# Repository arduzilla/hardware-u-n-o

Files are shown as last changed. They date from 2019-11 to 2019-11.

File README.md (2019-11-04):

# hardware-u-n-o

Arduino Uno format board

- Microconroller: STM32H750VB 
  - 416MHz Clock (Max 480)
  - Code & Data cache
  - 1MB SRAM
  - 128KB Flash + 2MB QSPI (direct execution from the QSPI)
  - plenty of peripherals
- RS485
- 6x Servo connector
- ... and much more

how to edit the schematics and the board layout:

install Eagle (free software for non commercial use)  https://www.autodesk.co.uk/products/eagle/free-download

clone (or fork) the arduzilla repo:
```
git clone https://github.com/arduzilla/hardware-u-n-o.git
```

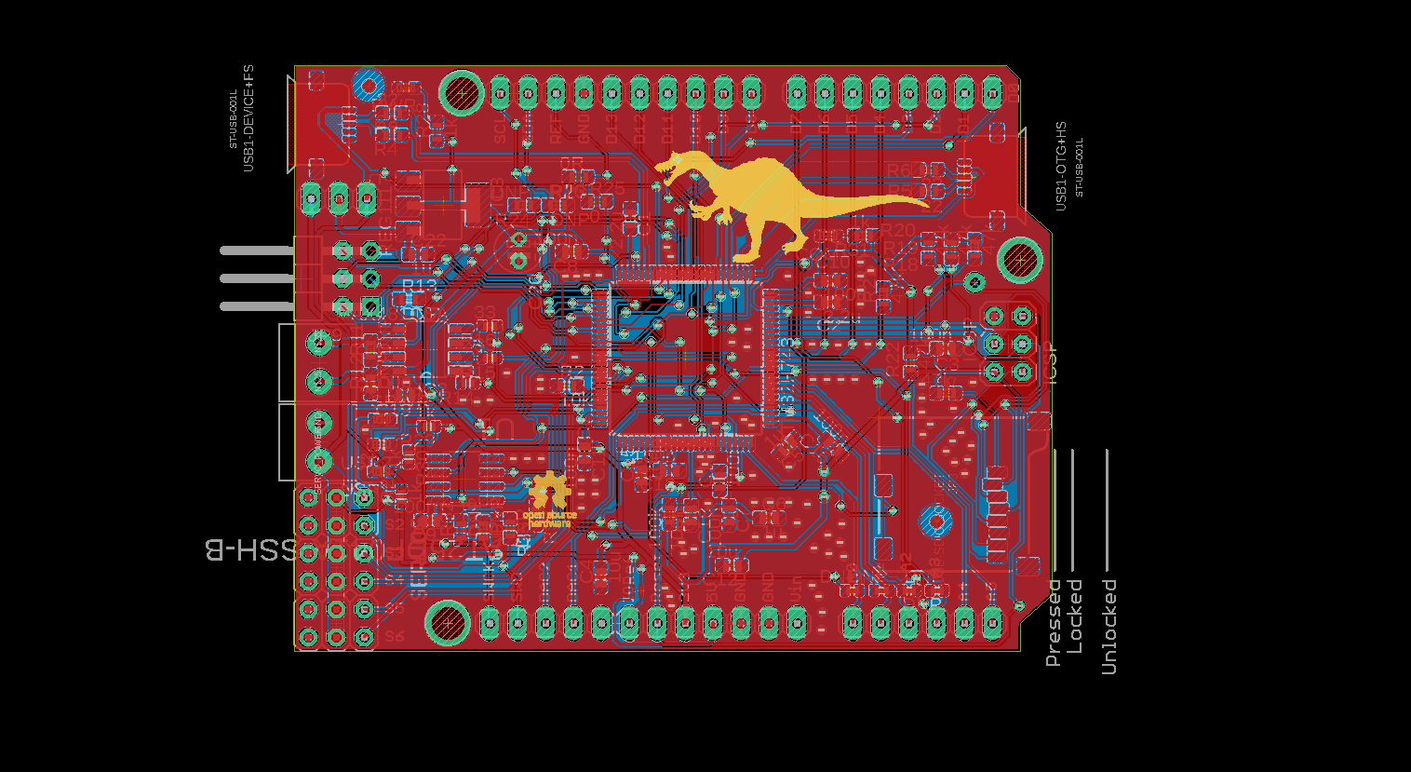
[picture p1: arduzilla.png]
arduzilla


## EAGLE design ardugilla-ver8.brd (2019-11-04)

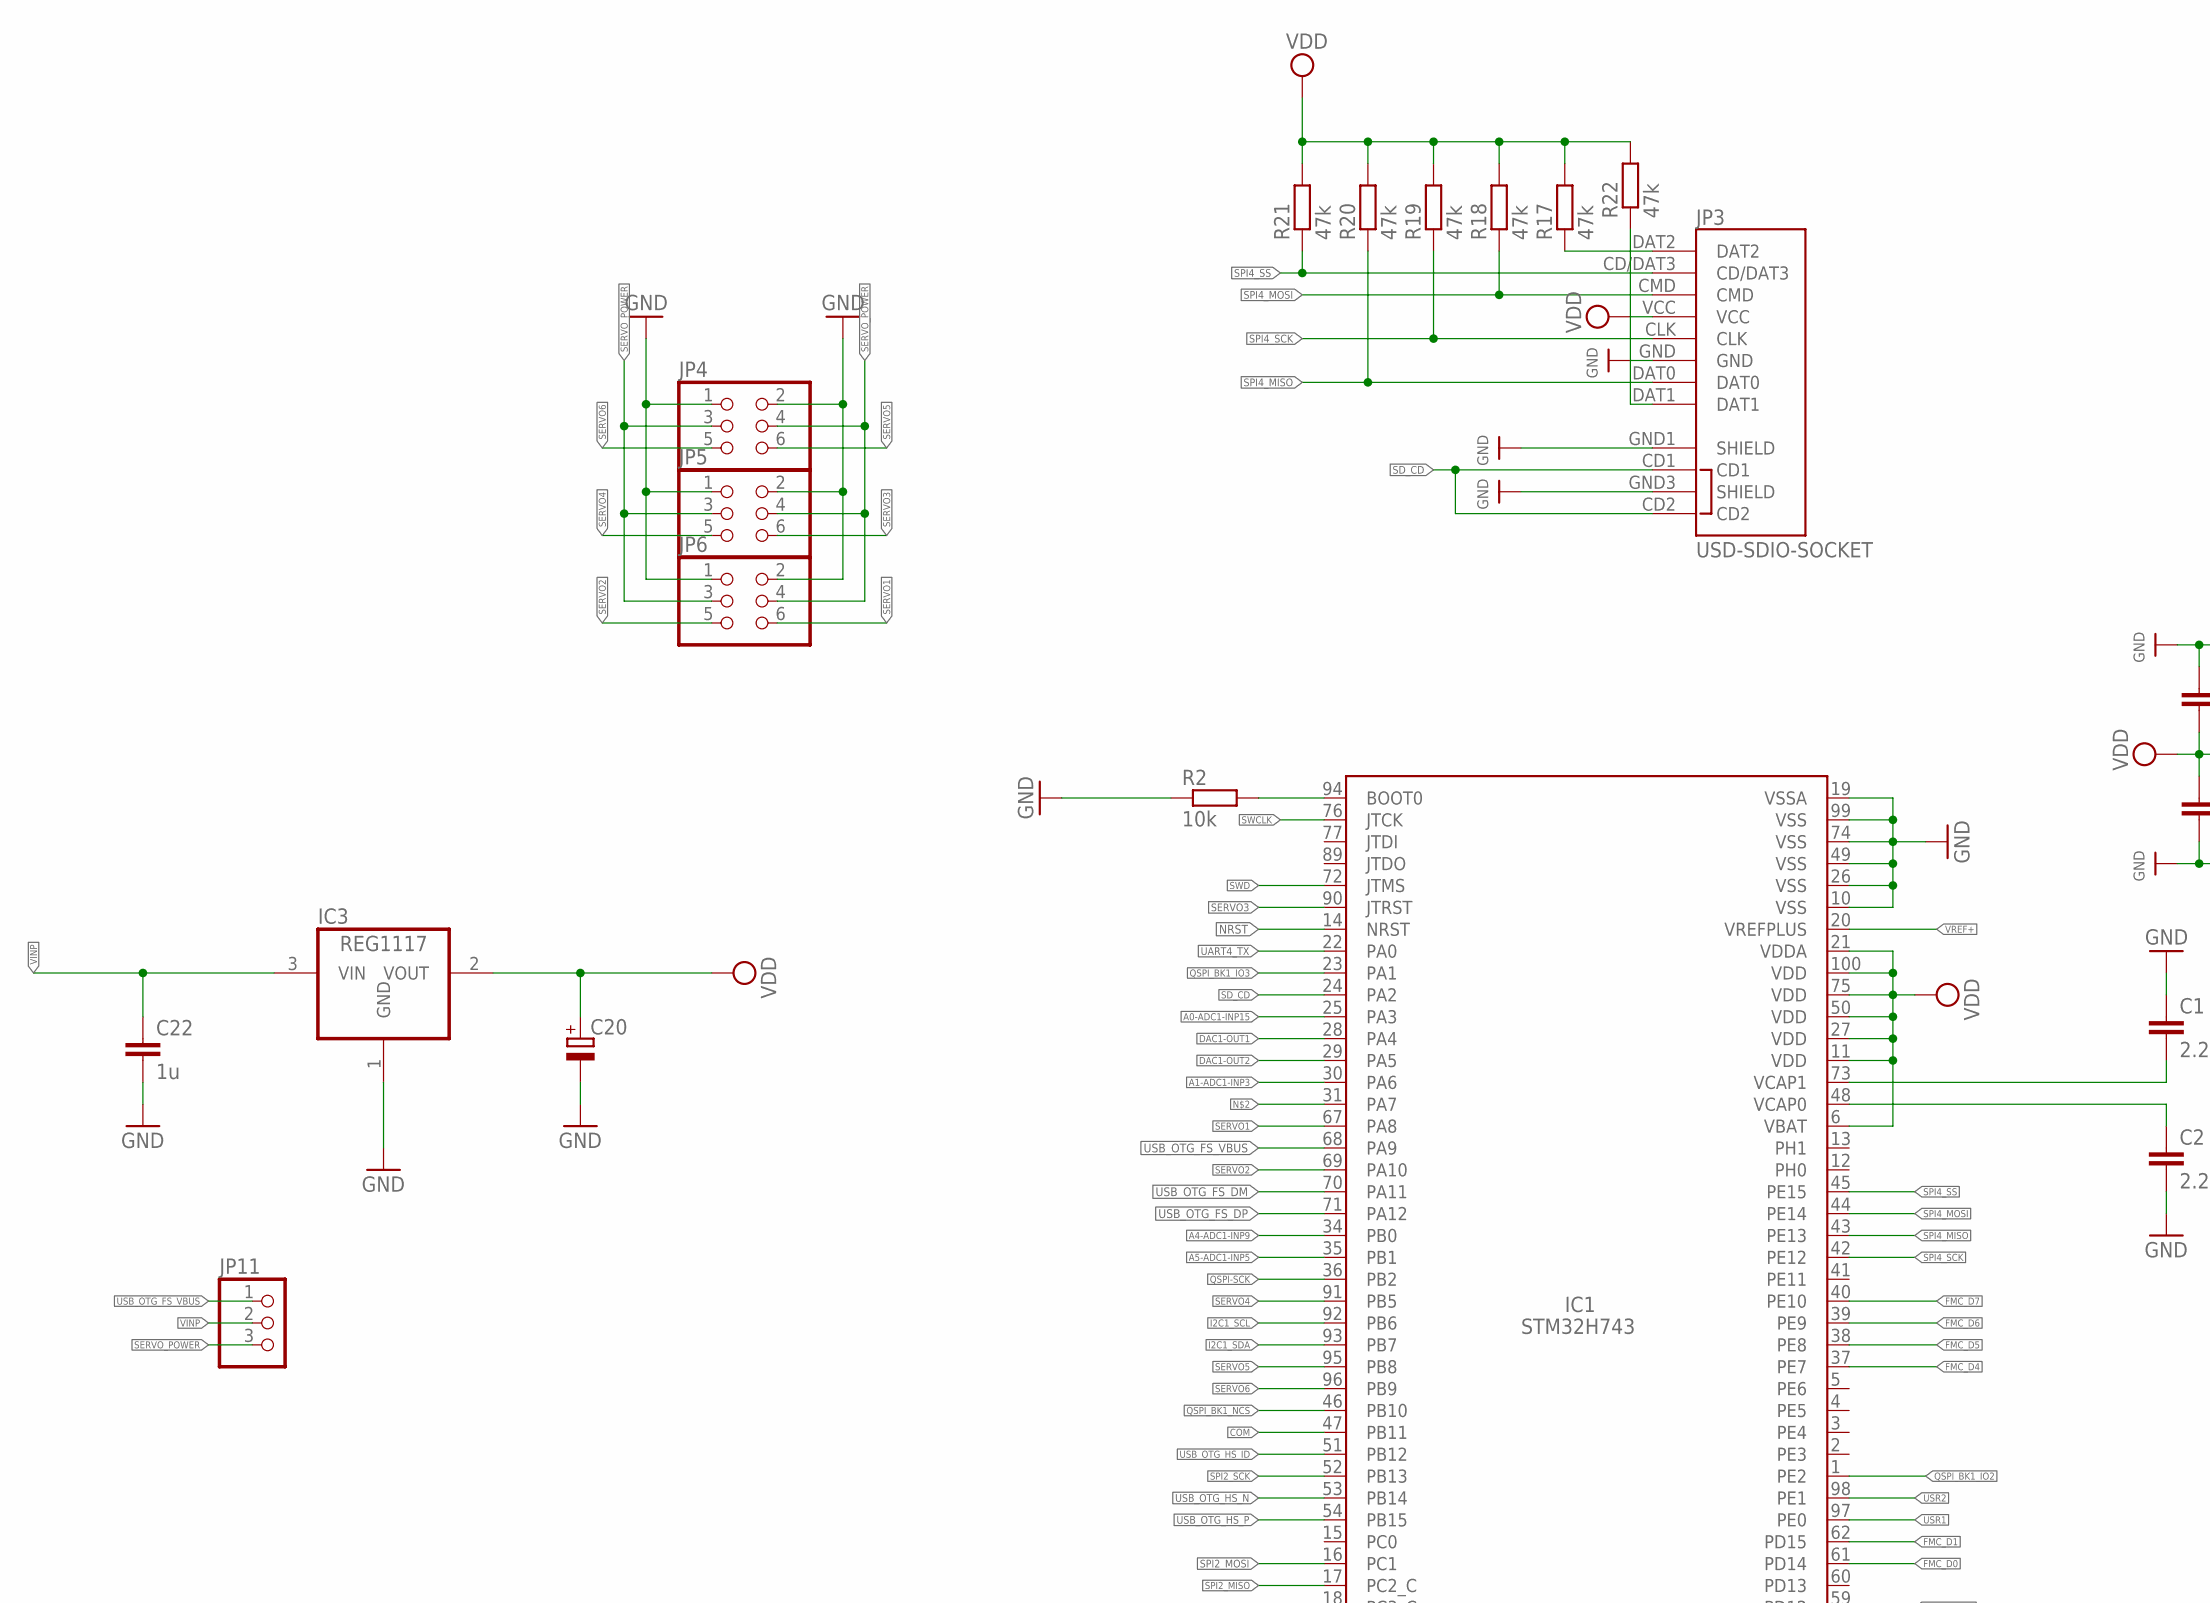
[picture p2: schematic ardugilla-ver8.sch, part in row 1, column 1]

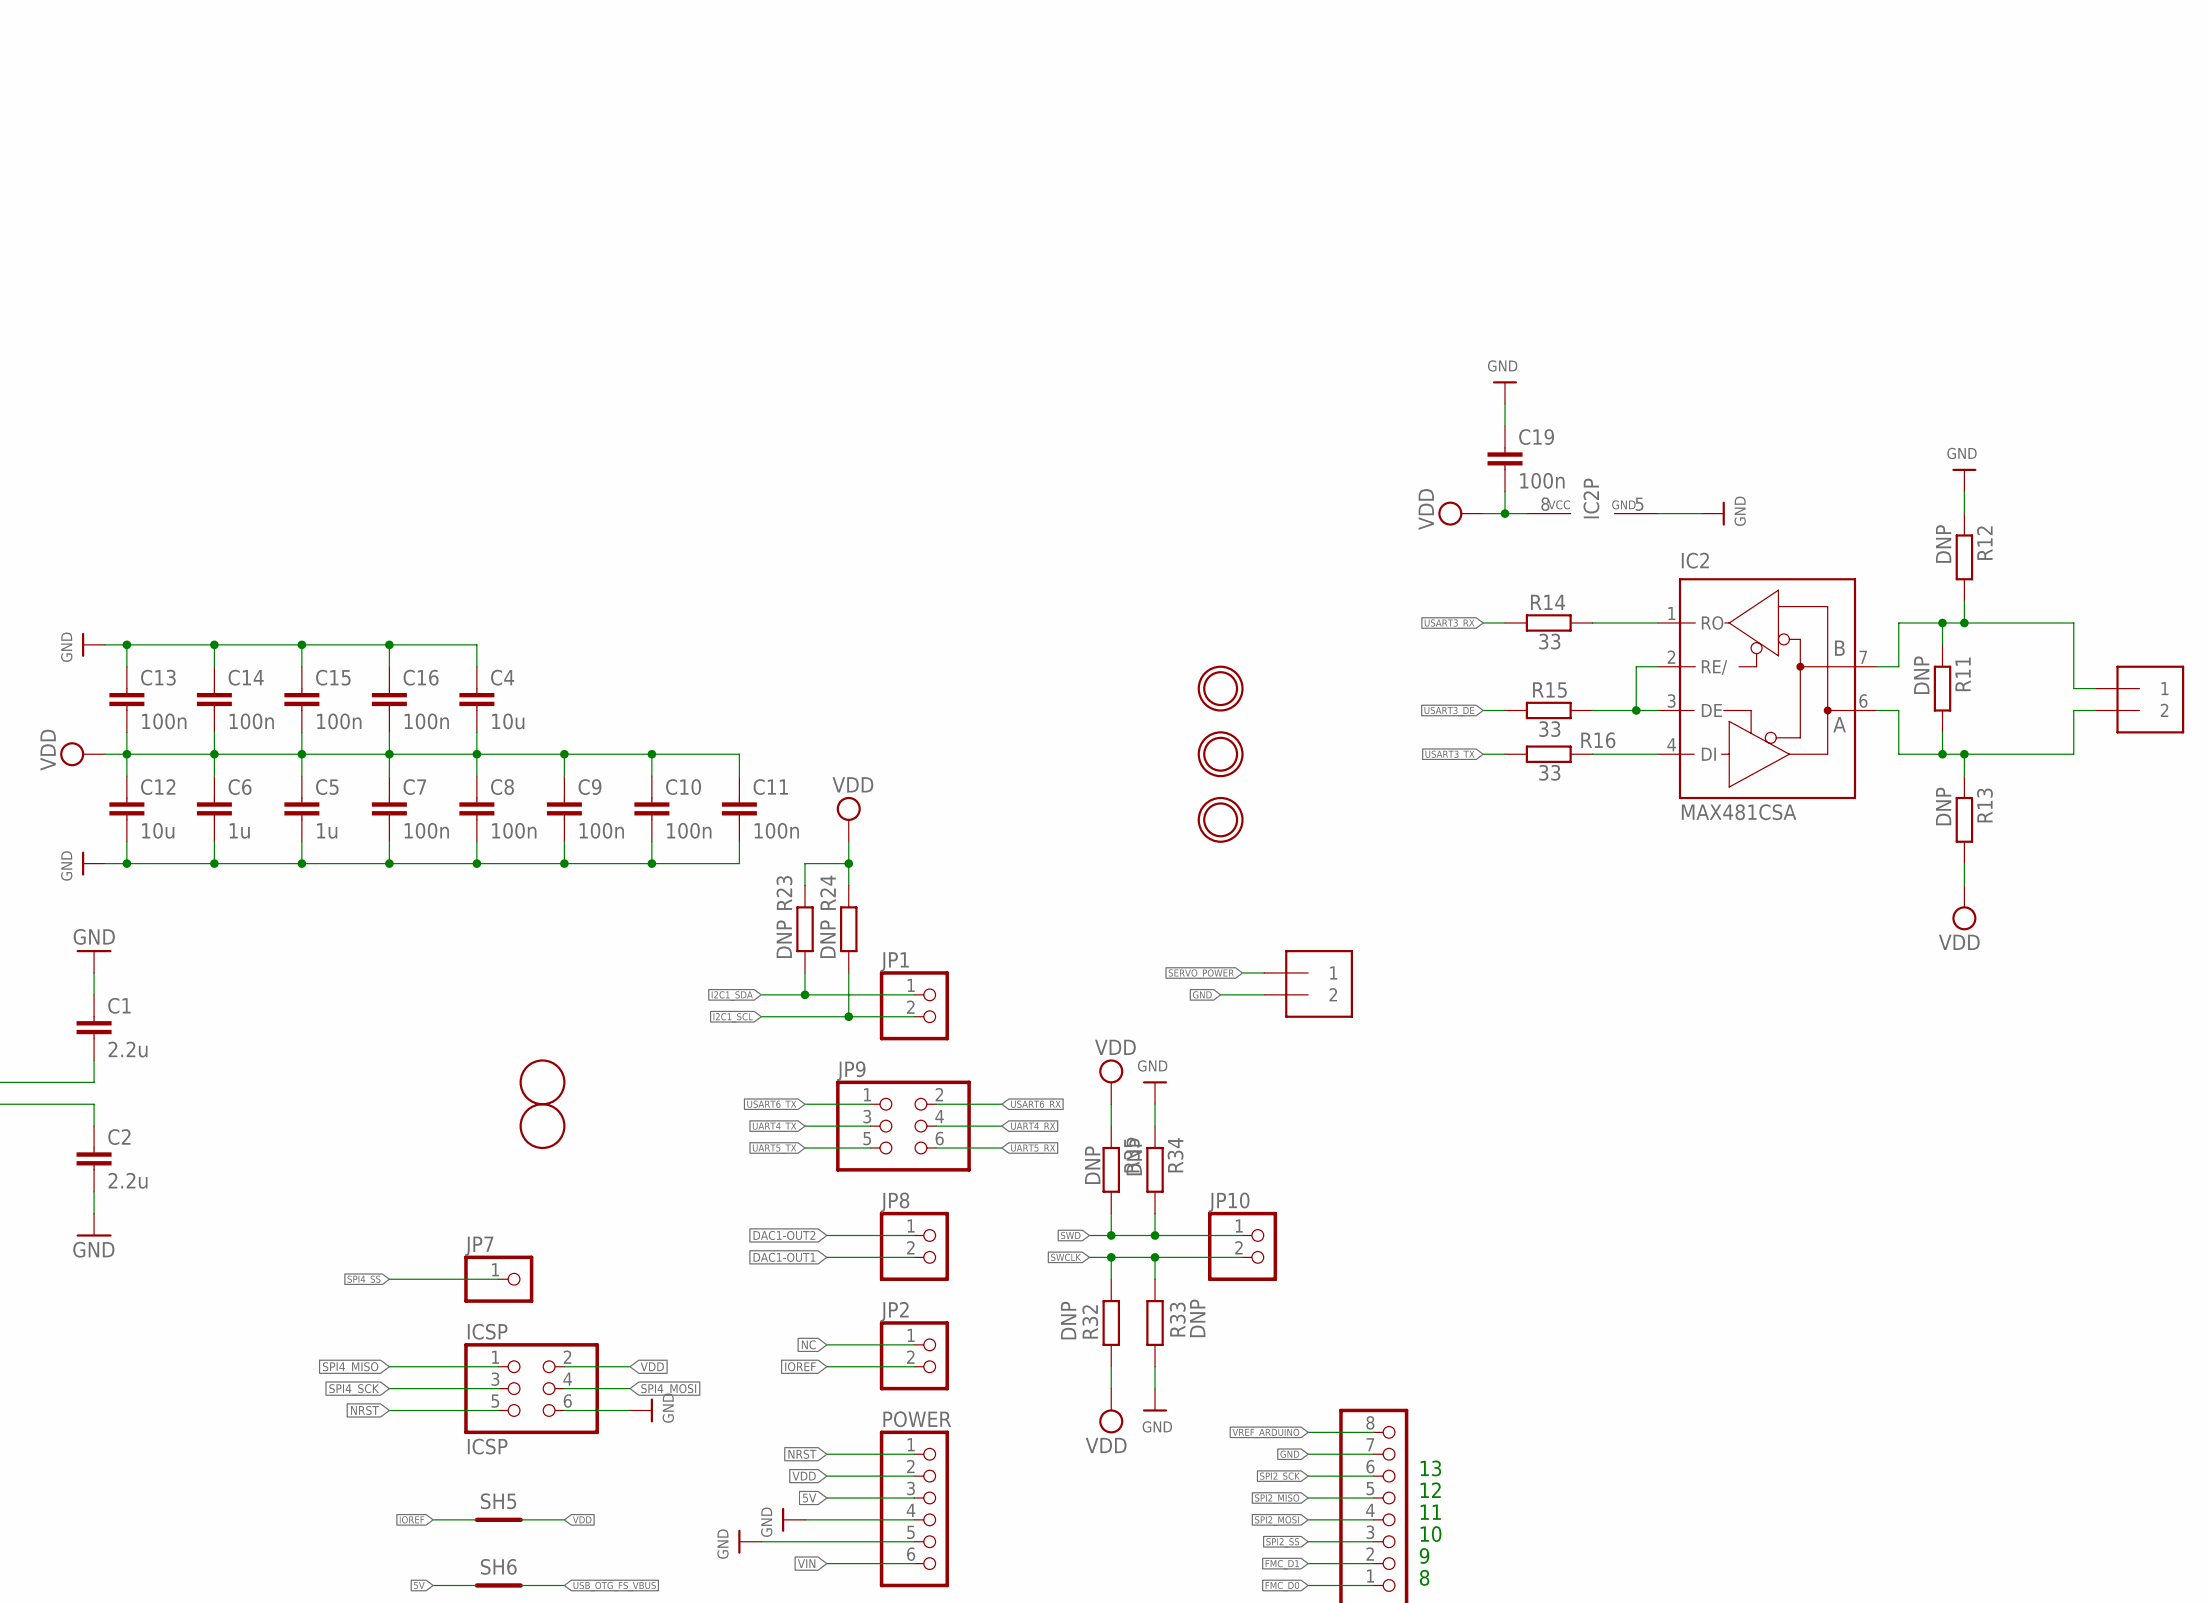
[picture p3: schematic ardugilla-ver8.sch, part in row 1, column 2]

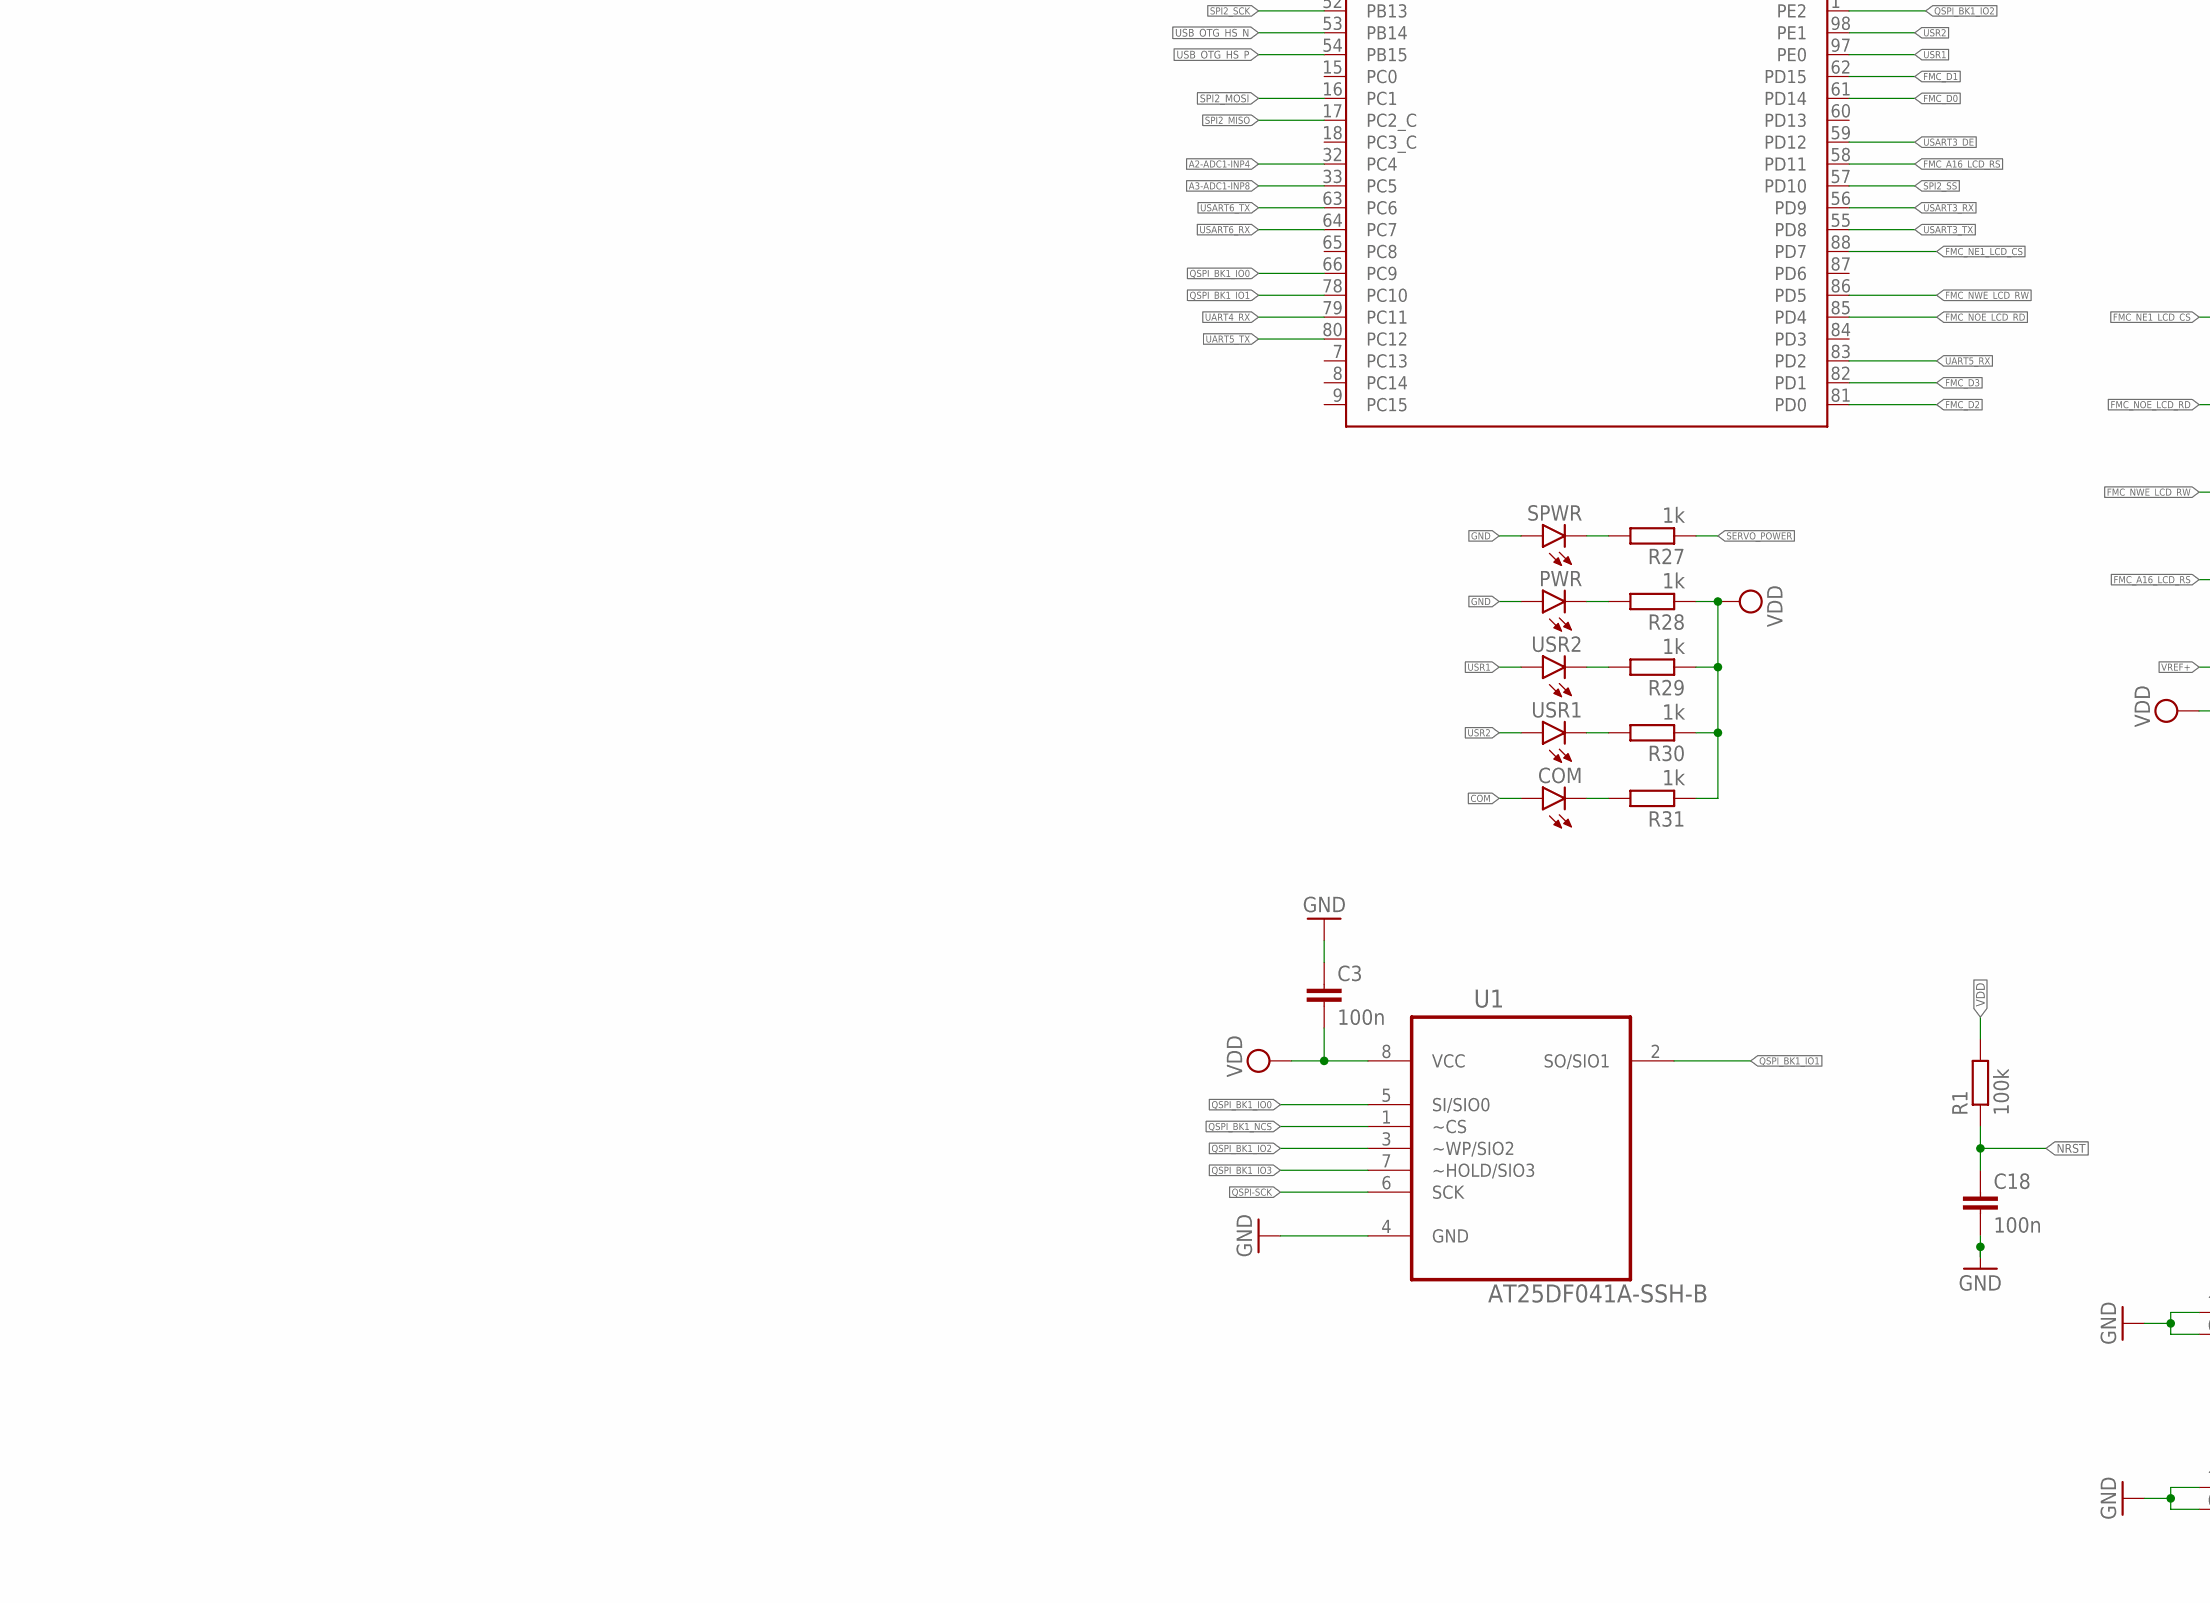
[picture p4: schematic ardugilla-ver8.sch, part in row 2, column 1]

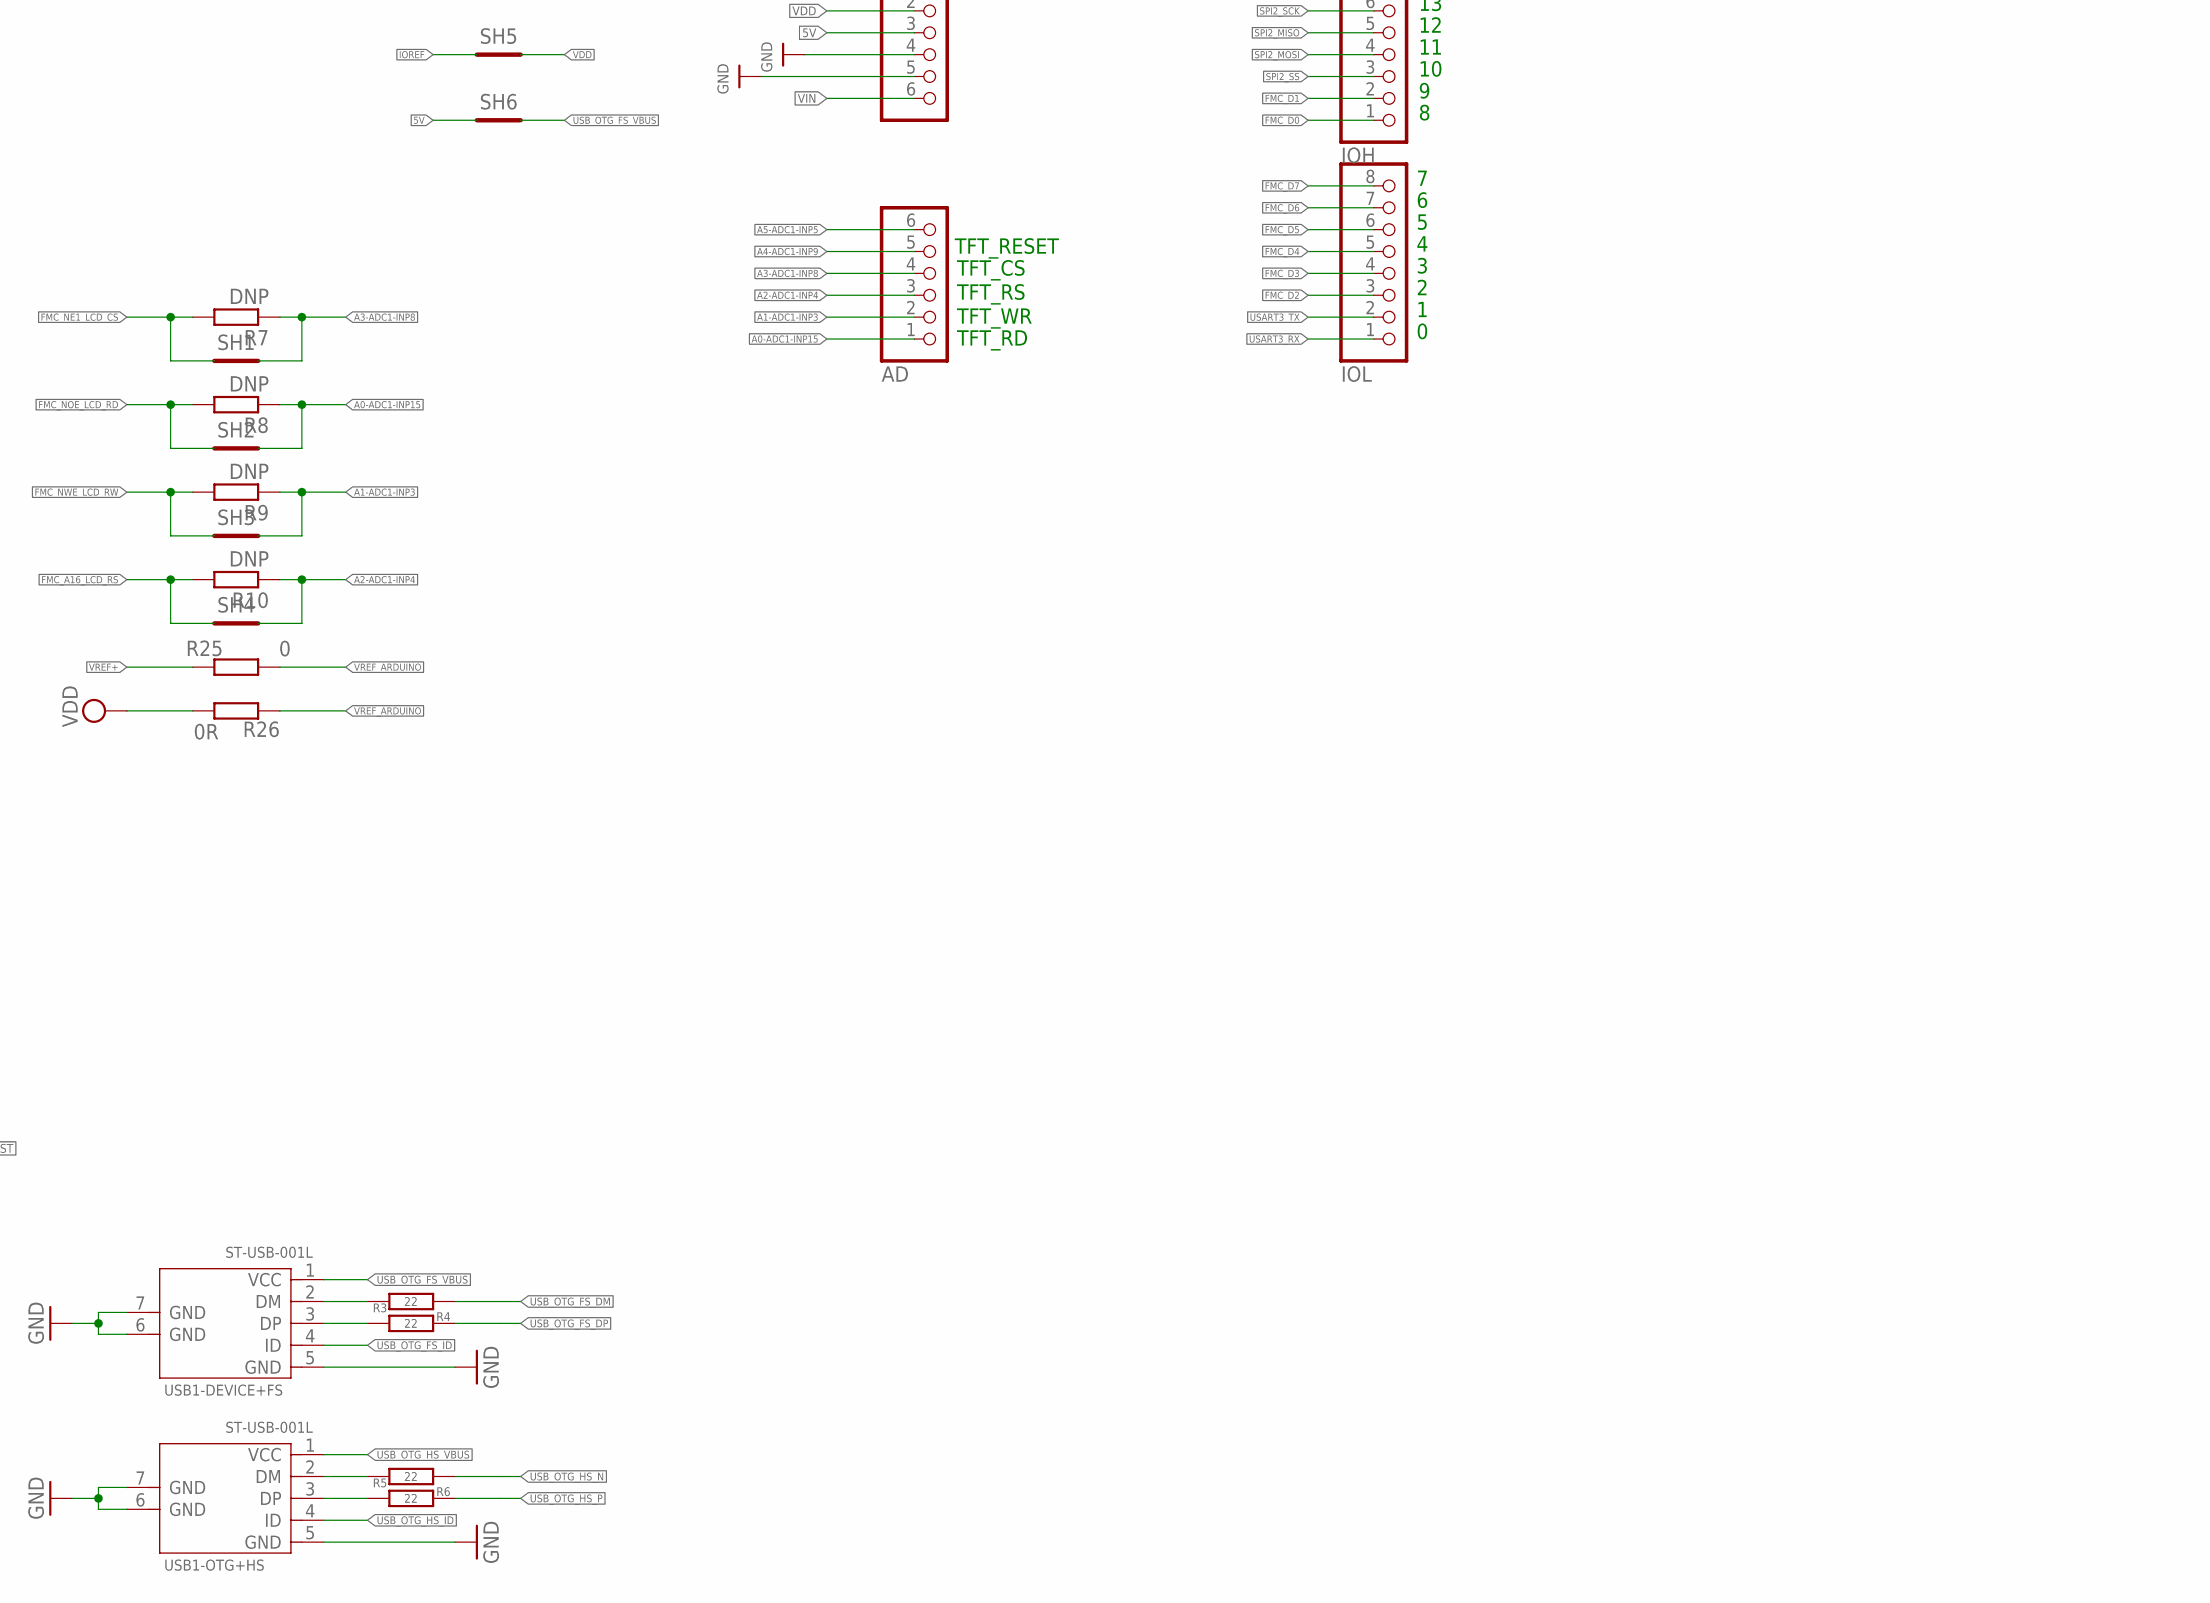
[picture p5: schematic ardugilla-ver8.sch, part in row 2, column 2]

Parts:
AD: PINHD-1X6; 1X06
C1, C2: 2.2u; C0603
C3, C7, C8, C9, C10, C11, C13, C14, C15, C16, C18, C19: 100n; C0603
C4, C12: 10u; C0603
C5, C6, C22: 1u; C0603
C20: CPOL-EUE2-4; E2-4
COM: LEDSML0603; SML0603
IC1: STM32H743; LQFP100_PACKAGE
IC2: MAX481CSA; SO08
IC3: REG1117; SOT223
ICSP: ICSP; 2X03
IOH: PINHD-1X8; 1X08
IOL: PINHD-1X8; 1X08
J1, J2: 1X2-3.5MM
JP1, JP2, JP8, JP10: PINHD-1X2; 1X02
JP3: USD-SDIO-SOCKET; MICRO-SD-SOCKET-SDIO
JP4, JP5, JP6: PINHD-2X3; 2X03
JP7: PINHD-1X1CB; 1X01-CLEANBIG
JP9: PINHD-2X03_2.54-90°; 2X03/90
JP11: PINHD-1X3; 1X03
POWER: PINHD-1X6; 1X06
PWR: LEDSML0603; SML0603
R1: 100k; R0603
R2: 10k; R0603
R3, R4, R5, R6: 22; R0603
R7, R8, R9, R10: DNP; R0402
R11, R12, R13, R23, R24, R32, R33, R34, R35: DNP; R0603
R14, R15, R16: 33; R0402
R17, R18, R19, R20, R21, R22: 47k; R0603
R25: 0; R0603
R26: 0R; R0603
R27, R29, R30: 1k; R0402
R28, R31: 1k; R0603
SH1, SH2, SH3, SH4, SH5, SH6: SHORTT5; SHORT_TOP-50
SPWR: LEDSML0603; SML0603
U1: AT25DF041A-SSH-B; SOIC127P600X175-8N
U$3, U$4: FIDUCIALMOUNT; FIDUCIA-MOUNT
U$12, U$13, U$14: MICROBUILDER_MOUNTINGHOLE3.0THIN; MICROBUILDER_MOUNTINGHOLE_3.0_PLATEDTHIN
USB1-DEVICE+FS, USB1-OTG+HS: ST-USB-001L; MICRO-USB5+2P-SMD-0.65
USR1, USR2: LEDSML0603; SML0603

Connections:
5V: POWER.3, SH6.1
A0-ADC1-INP15: AD.1, IC1.25 (PA3), R8.1, SH2.2
A1-ADC1-INP3: AD.2, IC1.30 (PA6), R9.1, SH3.2
A2-ADC1-INP4: AD.3, IC1.32 (PC4), R10.1, SH4.2
A3-ADC1-INP8: AD.4, IC1.33 (PC5), R7.1, SH1.2
A4-ADC1-INP9: AD.5, IC1.34 (PB0)
A5-ADC1-INP5: AD.6, IC1.35 (PB1)
COM: COM.A, IC1.47 (PB11)
DAC1-OUT1: IC1.28 (PA4), JP8.2
DAC1-OUT2: IC1.29 (PA5), JP8.1
FMC_A16_LCD_RS: IC1.58 (PD11), R10.2, SH4.1
FMC_D0: IC1.61 (PD14), IOH.1
FMC_D1: IC1.62 (PD15), IOH.2
FMC_D2: IC1.81 (PD0), IOL.3
FMC_D3: IC1.82 (PD1), IOL.4
FMC_D4: IC1.37 (PE7), IOL.5
FMC_D5: IC1.38 (PE8), IOL.6
FMC_D6: IC1.39 (PE9), IOL.7
FMC_D7: IC1.40 (PE10), IOL.8
FMC_NE1_LCD_CS: IC1.88 (PD7), R7.2, SH1.1
FMC_NOE_LCD_RD: IC1.85 (PD4), R8.2, SH2.1
FMC_NWE_LCD_RW: IC1.86 (PD5), R9.2, SH3.1
GND: C1.1, C2.2, C3.1, C4.1, C5.2, C6.2, C7.2, C8.2, C9.2, C10.2, C11.2, C12.2, C13.1, C14.1, C15.1, C16.1, C18.2, C19.1, C20.-, C22.2, IC1.10 (VSS), IC1.19 (VSSA), IC1.26 (VSS), IC1.49 (VSS), IC1.74 (VSS), IC1.99 (VSS), IC2.5 (GND), IC3.1 (GND), ICSP.6, IOH.7, J2.2, JP3.GND, JP3.GND1 (SHIELD), JP3.GND3 (SHIELD), JP4.1, JP4.2, JP5.1, JP5.2, JP6.1, JP6.2, POWER.4, POWER.5, PWR.A, R2.1, R12.1, R33.2, R34.1, SPWR.A, U1.4 (GND), USB1-DEVICE+FS.5 (GND), USB1-DEVICE+FS.6 (GND), USB1-DEVICE+FS.7 (GND), USB1-OTG+HS.5 (GND), USB1-OTG+HS.6 (GND), USB1-OTG+HS.7 (GND)
I2C1_SCL: IC1.92 (PB6), JP1.2, R24.1
I2C1_SDA: IC1.93 (PB7), JP1.1, R23.1
IOREF: JP2.2, SH5.1
unnamed: IC1.94 (BOOT0), R2.2
unnamed: C1.2, IC1.73 (VCAP1)
unnamed: C2.1, IC1.48 (VCAP0)
unnamed: R27.2, SPWR.C
unnamed: R3.2, USB1-DEVICE+FS.2 (DM)
unnamed: PWR.C, R28.2
unnamed: R4.2, USB1-DEVICE+FS.3 (DP)
unnamed: R5.2, USB1-OTG+HS.2 (DM)
unnamed: R6.2, USB1-OTG+HS.3 (DP)
unnamed: R29.2, USR2.C
unnamed: R30.2, USR1.C
unnamed: COM.C, R31.2
unnamed: IC2.2 (RE/), IC2.3 (DE), R15.2
unnamed: IC2.4 (DI), R16.2
unnamed: IC2.1 (RO), R14.2
unnamed: IC2.7 (B), J1.1, R11.1, R12.2
unnamed: IC2.6 (A), J1.2, R11.2, R13.1
NC: JP2.1
NRST: C18.1, IC1.14 (NRST), ICSP.5, POWER.1, R1.1
QSPI-SCK: IC1.36 (PB2), U1.6 (SCK)
QSPI_BK1_IO0: IC1.66 (PC9), U1.5 (SI/SIO0)
QSPI_BK1_IO1: IC1.78 (PC10), U1.2 (SO/SIO1)
QSPI_BK1_IO2: IC1.1 (PE2), U1.3 (~WP/SIO2)
QSPI_BK1_IO3: IC1.23 (PA1), U1.7 (~HOLD/SIO3)
QSPI_BK1_NCS: IC1.46 (PB10), U1.1 (~CS)
SD_CD: IC1.24 (PA2), JP3.CD1, JP3.CD2
SD_DAT1: JP3.DAT1, R22.1
SD_DAT2: JP3.DAT2, R17.1
SERVO1: IC1.67 (PA8), JP6.6
SERVO2: IC1.69 (PA10), JP6.5
SERVO3: IC1.90 (JTRST), JP5.6
SERVO4: IC1.91 (PB5), JP5.5
SERVO5: IC1.95 (PB8), JP4.6
SERVO6: IC1.96 (PB9), JP4.5
SERVO_POWER: J2.1, JP4.3, JP4.4, JP5.3, JP5.4, JP6.3, JP6.4, JP11.3, R27.1
SPI2_MISO: IC1.17 (PC2_C), IOH.5
SPI2_MOSI: IC1.16 (PC1), IOH.4
SPI2_SCK: IC1.52 (PB13), IOH.6
SPI2_SS: IC1.57 (PD10), IOH.3
SPI4_MISO: IC1.43 (PE13), ICSP.1, JP3.DAT0, R20.1
SPI4_MOSI: IC1.44 (PE14), ICSP.4, JP3.CMD, R18.1
SPI4_SCK: IC1.42 (PE12), ICSP.3, JP3.CLK, R19.1
SPI4_SS: IC1.45 (PE15), JP3.CD/DAT3, JP7.1, R21.1
SWCLK: IC1.76 (JTCK), JP10.2, R32.1, R33.1
SWD: IC1.72 (JTMS), JP10.1, R34.2, R35.2
UART4_RX: IC1.79 (PC11), JP9.4
UART4_TX: IC1.22 (PA0), JP9.3
UART5_RX: IC1.83 (PD2), JP9.6
UART5_TX: IC1.80 (PC12), JP9.5
USART3_DE: IC1.59 (PD12), R15.1
USART3_RX: IC1.56 (PD9), IOL.1, R14.1
USART3_TX: IC1.55 (PD8), IOL.2, R16.1
USART6_RX: IC1.64 (PC7), JP9.2
USART6_TX: IC1.63 (PC6), JP9.1
USB_OTG_FS_DM: IC1.70 (PA11), R3.1
USB_OTG_FS_DP: IC1.71 (PA12), R4.1
USB_OTG_FS_ID: USB1-DEVICE+FS.4 (ID)
USB_OTG_FS_VBUS: IC1.68 (PA9), JP11.1, SH6.2, USB1-DEVICE+FS.1 (VCC)
USB_OTG_HS_ID: IC1.51 (PB12), USB1-OTG+HS.4 (ID)
USB_OTG_HS_N: IC1.53 (PB14), R5.1
USB_OTG_HS_P: IC1.54 (PB15), R6.1
USB_OTG_HS_VBUS: USB1-OTG+HS.1 (VCC)
USR1: IC1.97 (PE0), USR2.A
USR2: IC1.98 (PE1), USR1.A
VDD: C3.2, C4.2, C5.1, C6.1, C7.1, C8.1, C9.1, C10.1, C11.1, C12.1, C13.2, C14.2, C15.2, C16.2, C19.2, C20.+, IC1.6 (VBAT), IC1.11 (VDD), IC1.21 (VDDA), IC1.27 (VDD), IC1.50 (VDD), IC1.75 (VDD), IC1.100 (VDD), IC2.8 (VCC), IC3.2 (VOUT), ICSP.2, JP3.VCC, POWER.2, R1.2, R13.2, R17.2, R18.2, R19.2, R20.2, R21.2, R22.2, R23.2, R24.2, R26.2, R28.1, R29.1, R30.1, R31.1, R32.2, R35.1, SH5.2, U1.8 (VCC)
VIN: POWER.6
VINP: C22.1, IC3.3 (VIN), JP11.2
VREF+: IC1.20 (VREFPLUS), R25.2
VREF_ARDUINO: IOH.8, R25.1, R26.1

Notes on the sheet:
TFT_RESET
TFT_CS
TFT_RS
TFT_WR
TFT_RD

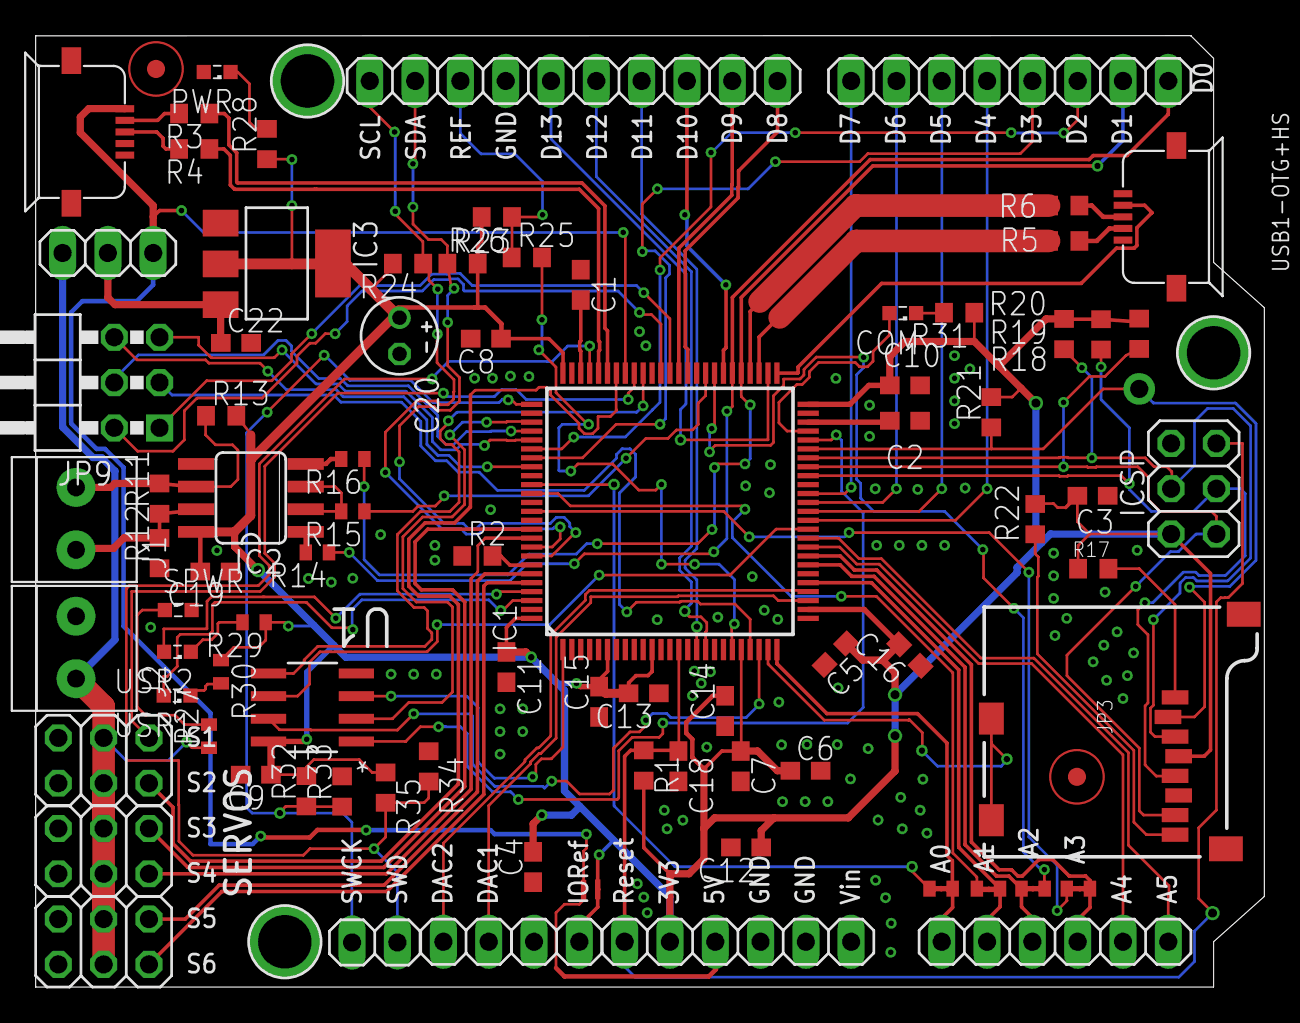
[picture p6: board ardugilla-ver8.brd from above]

Board: 2 copper layers, 68.9 x 53.3 mm, 95 parts (0 on the bottom side), 91 nets.

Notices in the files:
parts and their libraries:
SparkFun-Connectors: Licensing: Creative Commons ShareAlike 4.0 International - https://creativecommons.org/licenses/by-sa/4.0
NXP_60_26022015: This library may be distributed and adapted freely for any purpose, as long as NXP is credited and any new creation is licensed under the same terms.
